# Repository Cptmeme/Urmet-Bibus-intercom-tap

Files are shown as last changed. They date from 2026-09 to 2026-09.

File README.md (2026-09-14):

# telefoon_input: Urmet Bibus VOP intercom tap

Reverse-engineering the Urmet intercom (Artico monitor 1705/1 on bracket 1705/954,
Bibus 2nd Ed. VOP) so it can be bridged into Home Assistant.

| Path | What |
|---|---|
| `bus_tap/` | KiCad project for the analog tap board (L1/L2 + C1/C2 to ESP32 ADC), JLCPCB files in `bus_tap/jlc/` |
| `firmware/bus_tap_capture/` | ESP32 firmware streaming the tap's ADC channels over Wi-Fi/UDP |
| `host/` | `bustap`: record, analyse, decode and compare bus traffic |
| `docs/` | Urmet Bibus 2nd Ed. VOP technical manual, section 4B |
| `telefoon_input.kicad_sch` | reverse-engineered schematic of the AliExpress PC817 opto board |

Order of work: build the tap board, flash the firmware, run `bustap monitor` at the wall,
then record and decode. See `host/README.md`.

**Safety.** bus_tap GND is bus L2 and the tap is not isolated. While it is connected to
the intercom, the ESP32 runs from an isolated USB supply and talks over Wi-Fi only.

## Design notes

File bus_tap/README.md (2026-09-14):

# Urmet Bibus VOP — L1/L2 + C1/C2 analog tap

Front end that lets an ESP32 act as the oscilloscope we don't have, so we can
measure the modulation depth and bit timing on the Urmet door-phone bus.

Target hardware: **Urmet Bibus 2nd Ed. VOP**, Artico monitor Ref. 1705/1 on
bracket Ref. 1705/954. Manual in `../docs/`.

## Wiring

### Intercom side
| Board | Intercom terminal | Note |
|---|---|---|
| J1-1 | **L1** | bus positive (22.5 V idle as measured) |
| J1-2 | **L2** | becomes board GND |
| J2-1 | **C1** | floor call |
| J2-2 | **C2** | floor call |

Leave **VPI / VPU alone.** They carry the monitor's operating power
(700 mA, 16–18.5 Vdc), not just video.

### ESP32 side — J3
| J3 | ESP32 (classic DevKit) | Signal |
|---|---|---|
| 1 | 3V3 | supply for U1 |
| 2 | GND | **= bus L2** |
| 3 | GPIO34 | `ADC_DC`  — channel A, absolute bus voltage |
| 4 | GPIO35 | `ADC_AC`  — channel B, AC-coupled ×11 |
| 5 | GPIO36 (VP) | `ADC_FC` — channel C, floor call |

**Use ADC1 pins only.** ADC2 is unusable while Wi-Fi is on, and we need Wi-Fi
(see safety note below). GPIO34/35/36 are input-only, which suits analog.

## Channels

- **A — absolute.** R1/R2 divide by 11, U1A buffers, R3/C1 anti-alias at ~16 kHz.
  Window 0–34 V, so 22.5 V idle sits at 2.05 V. Shows big dips and the DC level.
- **B — AC-coupled, gain 11.** C2 blocks DC, R4/R5 re-bias to 1.65 V, U1B gains
  ×11. Net effect: **1 V of bus swing = 1 V at the ADC**, centred on 1.65 V,
  ±1.5 V before clipping, 3.2 Hz high-pass. This is the channel that will show
  small modulation and edges that channel A buries in quantisation noise.
- **C — floor call.** Same divider + buffer on C1/C2.

MCP6004 is CMOS (~1 pA bias), so the 1 MΩ divider costs ~1 µV of offset. Do not
substitute a bipolar op-amp such as LM324 — it is neither rail-to-rail nor
happy at 3.3 V, and its bias current would swamp the divider.

## Connector notes

There is **no separate external GND**. Board GND *is* bus L2 - it arrives on J1-2 and
leaves on J3-2 to the ESP32. Do not add a dedicated ground pin; the one thing this
board must not have is two references.

Mis-plugging is harmless: both bus channels use identical 1M/100k front ends, so
swapping the L1/L2 and C1/C2 headers does nothing bad, and reversing L1/L2 polarity
merely pins channel A at zero (D1 clamps at -0.3 V, the 1 M holds current to ~22 uA).

The one real risk is a wire that works loose and *dangles* behind the intercom, where
it could bridge L1 to L2. A disconnected tap is harmless - it is passive and
high-impedance, you just lose data - but a flapping conductor on a shared bus is not.
Use short leads with heat-shrink strain relief, or fit keyed/latching connectors
(JST-XH is 2.54 mm pitch, polarised, and JLC-stocked) if you want it fit-and-forget.

## Safety

1. **This tap is NOT isolated** — board GND is bus L2. Power the ESP32 from an
   isolated USB wall wart and get data off over **Wi-Fi/UDP**. Never plug the
   laptop's USB in while J1 is connected to the bus; that would tie the
   building's bus rail to your laptop's ground.
2. **Bus loading:** 22.5 V / 1.1 MΩ ≈ **20 µA**. The manual specs the whole
   monitor's standby draw on L1/L2 as **1.6 mA max**, so this tap is ~1.3% of
   it. This is why the PC817 opto board must not go here — at 3.3 kΩ it would
   draw 5.9 mA, ~3.7× the entire monitor.
3. **JP1** links C2 to board GND. Fit it **only** after confirming with a
   multimeter that the C1/C2 loop shares a reference with L2. If that loop
   floats, leave JP1 open and sense C1/C2 with the separate opto board — C1/C2
   is local to this monitor only, so nothing there can affect neighbours.

## JLCPCB part status

Checked against JLCPCB's Economic Parts list (Basic + Preferred Extended = $0 feeder
fee). Everything below is in that list **except** the three noted.

| Part | LCSC | Library | Note |
|---|---|---|---|
| R 1k 0402 | C11702 | Basic | |
| R 10k 0402 | C25744 | Basic | |
| R 100k 0402 | C25741 | Basic | |
| R 1M 0805 | C17514 | Basic | **150 V rated** |
| C 10n 0402 | C15195 | Basic | |
| C 100n 0402 | C1525 | Basic | |
| C 1u 0402 | C52923 | Basic | |
| C 10u 0402 | C15525 | Basic | 6.3 V X5R |
| BAT54S SOT-23 | C7420333 | Preferred Ext. | $0 fee, 1.2 M in stock |
| MCP6004T-I/SL | C7378 | **Extended** | feeder fee |
| 2.54 mm 1x02 header | - | **Extended** | no connectors are economic parts |
| 2.54 mm 1x05 header | - | **Extended** | " |

**3 unique Extended parts -> roughly $9 in one-off feeder fees.**

Why R1/R9 stay 0805: the 0402 1M (C26083) is rated **50 V**, the 0805 1M (C17514)
is **150 V**. R1/R9 take 10/11 of anything appearing on L1/L2, and the door strike
is inductive. This is the one place the extra millimetre is worth it.

### Cutting the feeder fees to zero

1. **Hand-solder the four headers.** They are the only through-hole parts and the
   only reason to pay for THT assembly at all. Removes 2 of the 3 Extended parts.
2. **Swap the quad for 2x MCP6002 (C7377, Preferred Extended, $0).** Two SOIC-8
   instead of one SOIC-14. Only 3 of the 4 amplifiers are used, so two duals give
   the same single spare. Costs a schematic edit and one more decoupling cap.

### Do NOT substitute LM324

`LM324DT` (C71035) is a Basic part, SOIC-14, and pin-compatible with the MCP6004.
It will not work here. Its input common-mode range is Vee to Vcc-1.5 V, i.e. 0 to
**1.8 V** on a 3.3 V rail - but channel A's input sits at **2.05 V**, outside that
range entirely. Its 45 nA input bias across the 90.9 kOhm source would also add
several mV of offset where the MCP6004's ~1 pA adds a microvolt. Same footprint,
free, and completely wrong.

## Files

| File | Purpose |
|---|---|
| `bom.csv` | full engineering BOM (refs, values, footprints, LCSC, JLC library) |
| `bom_jlcpcb.csv` | **upload this to JLCPCB** - Comment / Designator / Footprint / LCSC Part #, SMD only |
| `bus_tap.pdf` | schematic print |
| `erc.rpt` | ERC report |

`bom_jlcpcb.csv` covers 21 assembled parts over 10 lines. J1, J2, J3 and JP1 are
deliberately excluded - they are the only through-hole parts, they are the only
Extended parts left once the MCP6004 fee is paid, and hand-fitting four headers takes
minutes. Designators are written as explicit lists (`R2,R4,R5,R6,R10`), not KiCad's
default ranges (`R4-R6`), which JLC's BOM parser does not understand.

Each symbol carries `LCSC` and `JLC` fields, so both BOMs regenerate straight from
the schematic.

## JLCPCB upload files (`jlc/`)

| File | Upload as |
|---|---|
| `bus_tap-gerbers.zip` | PCB (11 fab layers, gerber drill included) |
| `bom_jlc.csv` | BOM - `Comment / Designator / Footprint / LCSC Part #` |
| `cpl_jlc.csv` | CPL - `Designator / Mid X / Mid Y / Layer / Rotation` |

J1, J2, J3 and JP1 are excluded from both CSVs (hand-soldered). BOM and CPL
designators cross-check: 21 each, no orphans.

### CPL rotation corrections - ALREADY APPLIED to cpl_jlc.csv

JLC's library orientation differs from KiCad's for two packages here. Determined
empirically from JLC's upload preview, and **baked into `cpl_jlc.csv`**:

| Part | Package | KiCad rot | Correction | CPL value |
|---|---|---|---|---|
| D1 | SOT-23 | 0 | +180 | **180** |
| D2 | SOT-23 | 180 | +180 | **0** |
| U1 | SOIC-14 | 0 | -90 (90 CW) | **270** |

Rotation in the CPL is **counter-clockwise-positive**, matching KiCad's own pos file
(which emits -90 for C6/C7 and +90 for R10). KiCad places SOIC-14 with the long axis
vertical and pin 1 top-left; JLC's library has it horizontal, hence the 90 deg.

The 18 chip R/C parts need no correction - they are two-terminal and non-polarised,
so 0 vs 180 is electrically identical.

**Verification on next upload: the preview should need NO manual rotation.** If any of
these three still looks wrong, the correction above is stale - re-derive it rather than
nudging it in the preview.

## Status

- Schematic: complete, hand-tidied in eeschema, **ERC clean (0 violations)**, netlist verified unchanged.
- Footprints: **assigned on all 25 parts**, 9 distinct footprints, all verified present in the KiCad libraries.
- PCB: not started. Target is JLCPCB Economic PCBA. Run **Tools > Update PCB from Schematic (F8)** in the PCB editor to seed it.

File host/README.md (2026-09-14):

# bustap: record and decode the Urmet bus

Protocol-discovery tools for the bus_tap board. They don't assume an encoding: they
find activity, work out how bits are encoded from pulse timing, decode with every
plausible scheme, rank the results, and line up frames from different events so the
address, command and checksum fields stand out.

## Setup

```sh
cd host
python3 -m venv .venv
.venv/bin/pip install -r requirements.txt
.venv/bin/python -m unittest discover -s tests      # a few seconds, no hardware needed
```

Run commands from `host/` as `.venv/bin/python -m bustap ...`.

## At the intercom

1. Flash the firmware (see `firmware/bus_tap_capture/README.md`). Power the ESP32 from an
   **isolated** USB supply, wire J3, then J1 (L1/L2) and J2 (C1/C2).
2. **`bustap monitor`**: the first sanity check. Idle DC should read about **22.5 V**; ~0 V
   usually means L1/L2 are swapped, which is harmless. Watch `lost`, `gaps` and `ovf`
   stay at 0.
3. **Record labelled events**, one label per kind of event:
   ```sh
   bustap record --gated --label ring_own        # ring your own bell at the street panel
   bustap record --gated --label door_open       # press the door-release button
   bustap record --gated --label handset_up
   bustap record --gated --label floor_call      # your own landing button (C1/C2)
   ```
   Each burst of activity becomes its own file in `captures/`, with a second of history
   before the trigger. Calls to other flats also travel over L1/L2; capture a few, since
   the difference between your address and another is what exposes the address field.
4. **`bustap analyze captures/*.npz --plots plots/`**, per event: which channel was used,
   the pulse and gap clusters as multiples of one time unit, ranked encoding
   hypotheses, and the best decodes with their error counts. Look at the plots too.
5. **`bustap compare captures/*.npz`**, per bit position:
   `=` is identical everywhere (preamble/sync), `L` changes only between labels
   (address/command), `*` varies within a label (counter, checksum). It then searches
   for a checksum (sum, xor, CRC-8 variants) over the aligned frames.

## Reading the output honestly

- **`~ equally clean: ...`** means timing cannot choose between readings. Manchester and
  biphase-mark are *provably* interchangeable on the wire; a UART reading of fewer than
  four bytes can frame by chance. Run `compare` on both with `--decoder`, and keep the one
  that gives frames a stable preamble.
- **`CONFIRMED` checksums need at least 4 distinct frames.** With fewer, chance
  agreement across ~2500 combinations is likely and the result is marked `UNCONFIRMED`.
- **Frame edges.** A symbol at the bus's idle level at the start or end of a frame merges
  into the idle beside it. Manchester, UART, pulse-width and pulse-distance recover it.
  Biphase-mark can lose a final 0, and plain NRZ loses trailing idle-level bits: nothing
  on the wire marks where those frames end. A frame that is one bit value repeated
  (like `0x00` or `0xFF`) is ambiguous by half a bit in Manchester. Real frames with a
  preamble are not.
- **AC clipping.** Large dips saturate the AC channel. The report says so; timing is still
  good, and the DC channel carries the true levels.

## Without the intercom

```sh
bustap simulate manchester --payload a5120140 --label ring_own --out sim.npz
bustap analyze sim.npz
bustap fake-esp sim.npz --port 17777 &          # serves it over the real UDP protocol
bustap monitor --esp 127.0.0.1 --port 17777
```

`simulate` supports manchester, bmc, uart, pwm, pdm, nrz, fsk and dtmf, through a model
of the bus_tap channels and ESP32 ADC.

## Layout

| Module | Role |
|---|---|
| `protocol.py` | UDP wire format (mirrors `firmware/.../protocol.h`) |
| `record.py` | receiver, live monitor, fixed and activity-gated recording |
| `capture.py` | `.npz` capture files, raw codes to bus volts |
| `dsp.py` | noise, event detection, slicing, sub-sample edge timing |
| `infer.py` | duration clusters, time unit, encoding hypotheses |
| `decoders.py` | NRZ, UART, Manchester, biphase-mark, pulse-width, pulse-distance |
| `tones.py` | tone detection, FSK discriminator, DTMF |
| `compare.py` | frame alignment, field map, checksum search |
| `simulate.py`, `fake_esp.py` | synthetic traffic and a fake ESP for testing |

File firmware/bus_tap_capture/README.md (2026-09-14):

# bus_tap_capture

ESP32 firmware for the bus_tap board. Samples the three analog channels continuously
and streams them over Wi-Fi/UDP to the host tools in `host/`.

> **Safety.** bus_tap GND *is* Urmet bus L2. Flash and configure the ESP32 **before** it
> goes near the intercom. Once J1 is connected, power the ESP32 from an **isolated USB
> supply only** and never plug it into a computer. That is why data leaves over Wi-Fi.

## Build and flash (ESP-IDF 5.3)

```sh
cd firmware/bus_tap_capture
export IDF_PYTHON_ENV_PATH=$HOME/.espressif/python_env/idf5.3_py3.13_env
. $HOME/esp/esp-idf/export.sh
idf.py set-target esp32
idf.py menuconfig          # "Bus tap capture": Wi-Fi SSID and password
idf.py -p /dev/cu.usbserial-XXXX flash monitor
```

`IDF_PYTHON_ENV_PATH` is needed on this machine: without it `export.sh` picks Homebrew's
Python 3.14 and looks for a py3.14 IDF environment that does not exist.

The Wi-Fi password is stored in plain text in `sdkconfig`; don't share that file.

## Wiring: ESP32 DevKit to bus_tap J3

| J3 | ESP32 | Signal |
|---|---|---|
| 1 | 3V3 | op-amp supply |
| 2 | GND | = bus L2 |
| 3 | GPIO34 | DC, absolute bus voltage |
| 4 | GPIO35 | AC, bus swing |
| 5 | GPIO36 (VP) | FC, floor call |

ADC1 pins only; ADC2 does not work while Wi-Fi is on. Pins are configurable in menuconfig.

## Behaviour

- **Rate.** 60 kS/s total by default, shared by the enabled channels (20 kS/s each with
  all three). The host can change it at runtime, e.g.
  `python -m bustap monitor --ch AC --rate 60000` puts all 60 kS/s on the AC channel.
  Worth doing for fine timing: the board's anti-alias filter sits at ~16 kHz, above the
  10 kHz Nyquist limit you get with three channels sharing 60 kS/s.
- **Streaming** runs only while a host keeps sending `UBTHELLO` (5 s lease), to the host
  that sent the most recent one.
- **INFO** once a second: configuration, the eFuse calibration table, DMA overflow and
  Wi-Fi TX-drop counters, RSSI.
- **Protocol** is defined in `main/protocol.h`; `host/tests/test_protocol.py` compiles it
  and checks `host/bustap/protocol.py` against it.

## What has and hasn't been verified

Verified: builds for ESP32 on IDF 5.3.2 with no warnings from `main/`; the protocol
layout matches the host byte for byte; the host recorder, gap accounting and gated
recording pass against a protocol-identical fake on localhost.

**Not yet verified on hardware:** sustained 60 kS/s over your actual Wi-Fi, the real
ADC sample rate (the host measures it against `esp_timer`, so a few percent of error
is corrected rather than silently scaling pulse widths), and ADC behaviour at the
extremes. The ESP32 ADC compresses above about 2.45 V at 12 dB attenuation, so AC
channel swings beyond roughly +0.8 V read low. Timing is unaffected.

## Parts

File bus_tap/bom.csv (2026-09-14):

Reference | Value | Footprint | LCSC
C1,C4,C5 | 10n | Capacitor_SMD:C_0402_1005Metric | C15195
C2 | 1u | Capacitor_SMD:C_0402_1005Metric | C52923
C3,C7 | 10u | Capacitor_SMD:C_0402_1005Metric | C15525
C6 | 100n | Capacitor_SMD:C_0402_1005Metric | C1525
D1,D2 | BAT54S | Package_TO_SOT_SMD:SOT-23 | C7420333
J1 | L1/L2 | Connector_PinHeader_2.54mm:PinHeader_1x02_P2.54mm_Vertical
J2 | C1/C2 | Connector_PinHeader_2.54mm:PinHeader_1x02_P2.54mm_Vertical
J3 | ESP32 DevKit | Connector_PinHeader_2.54mm:PinHeader_1x05_P2.54mm_Vertical
JP1 | JUMPER | Connector_PinHeader_2.54mm:PinHeader_1x02_P2.54mm_Vertical
R1,R9 | 1M | Resistor_SMD:R_0805_2012Metric | C17514
R2,R4-R6,R10 | 100k | Resistor_SMD:R_0402_1005Metric | C25741
R3,R8,R11 | 1k | Resistor_SMD:R_0402_1005Metric | C11702
R7 | 10k | Resistor_SMD:R_0402_1005Metric | C25744
U1 | MCP6004 | Package_SO:SOIC-14_3.9x8.7mm_P1.27mm | C7378

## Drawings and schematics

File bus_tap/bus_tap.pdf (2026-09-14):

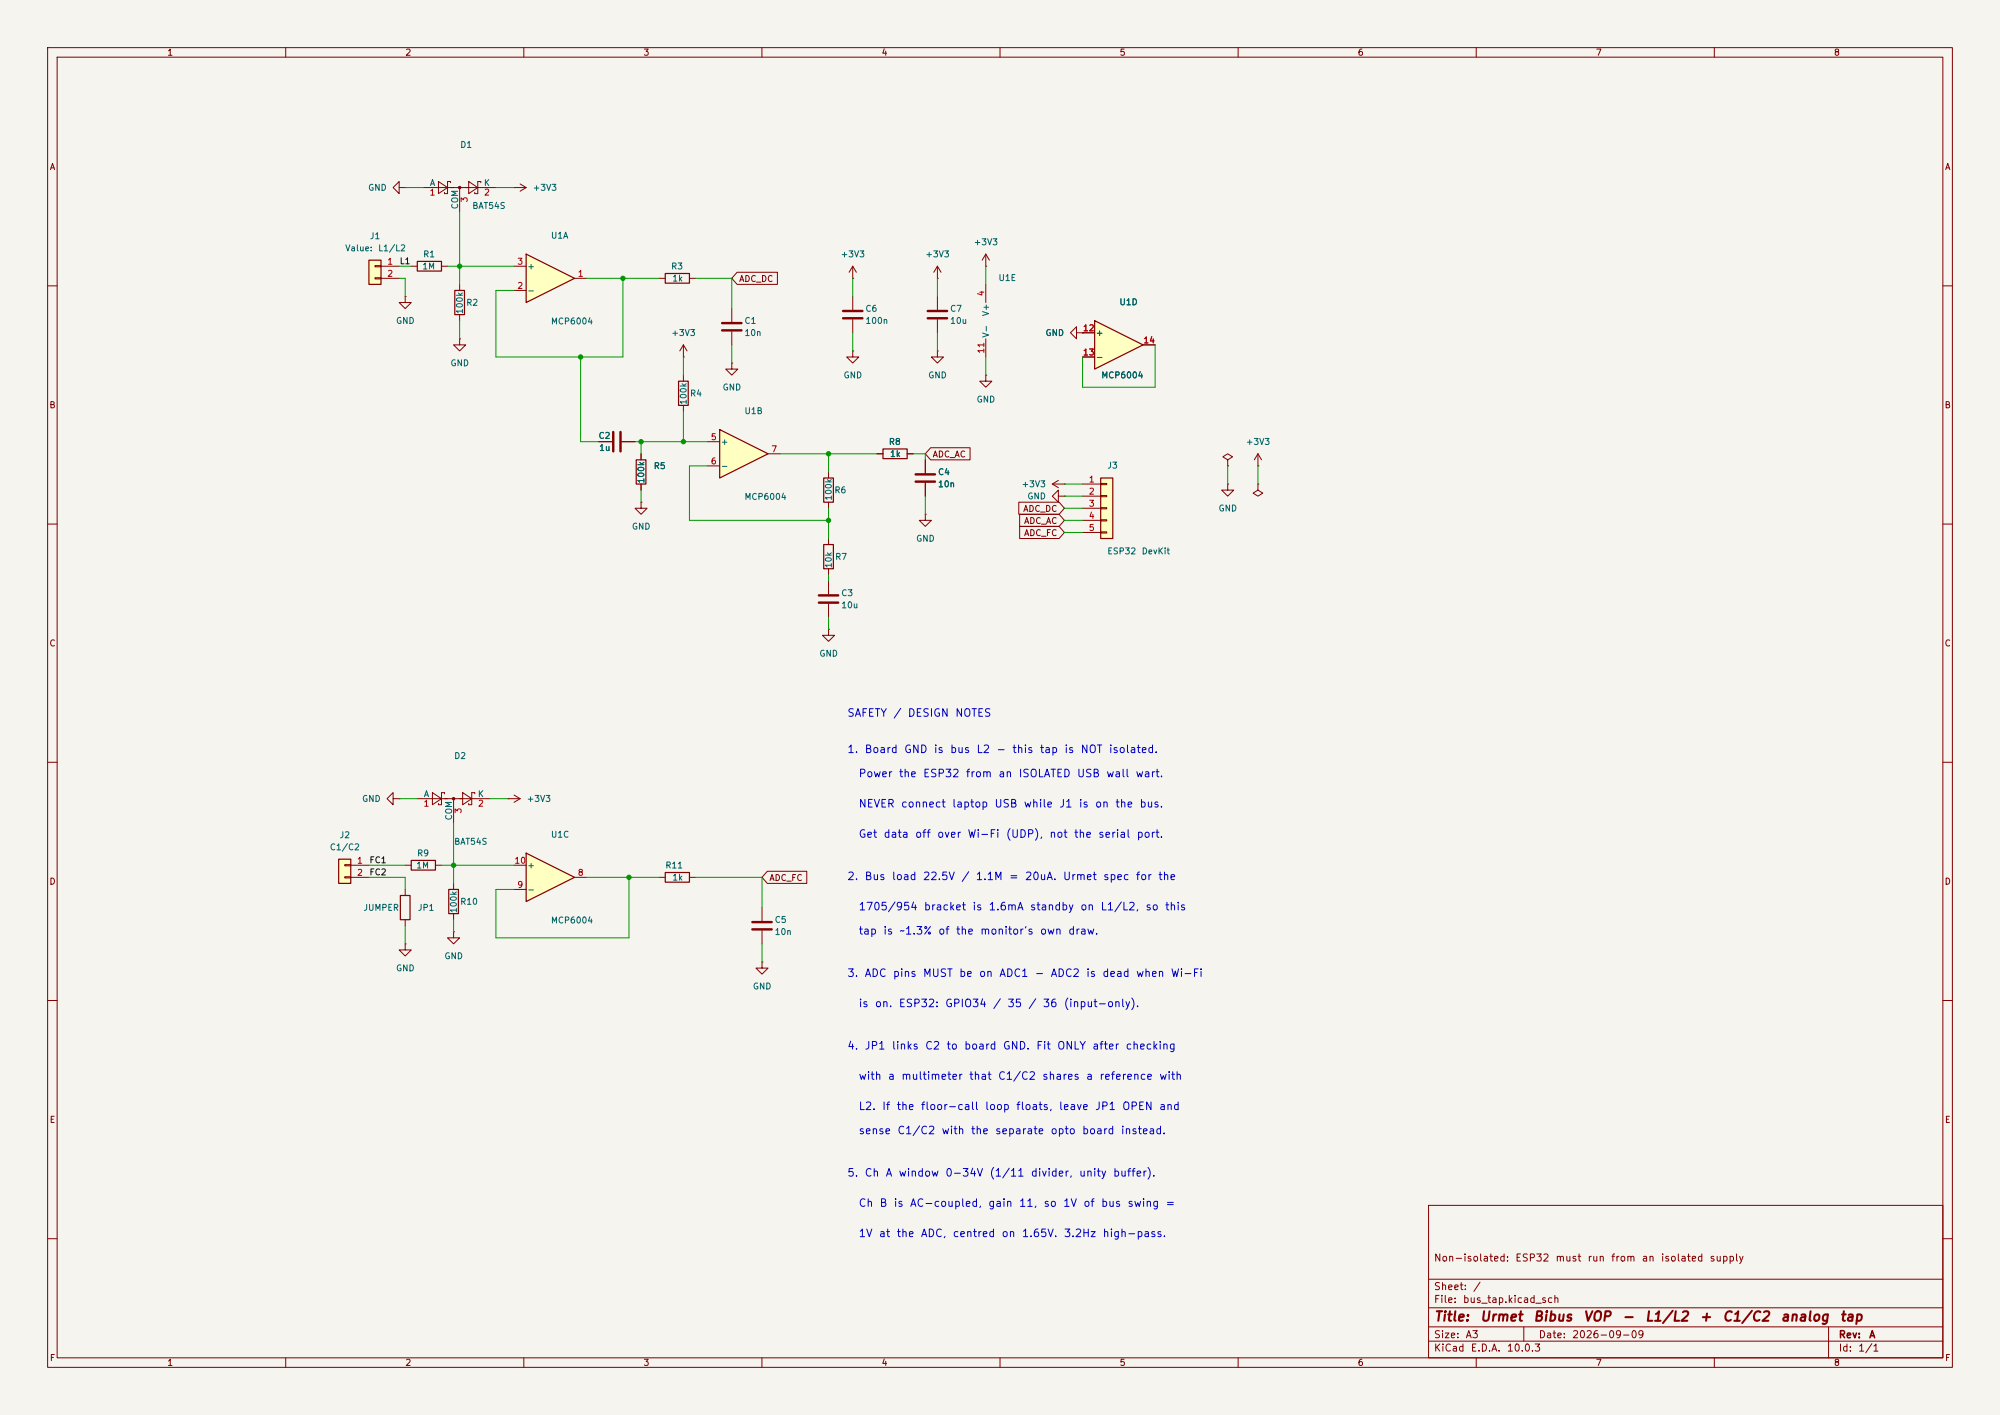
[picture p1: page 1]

1. Board GND is bus L2 - this tap is NOT isolated.

Power the ESP32 from an ISOLATED USB wall wart.

NEVER connect laptop USB while J1 is on the bus.

Get data off over Wi-Fi (UDP), not the serial port.

2. Bus load 22.5V / 1.1M = 20uA. Urmet spec for the

1705/954 bracket is 1.6mA standby on L1/L2, so this

tap is ~1.3% of the monitor's own draw.

3. ADC pins MUST be on ADC1 - ADC2 is dead when Wi-Fi

is on. ESP32: GPIO34 / 35 / 36 (input-only).

4. JP1 links C2 to board GND. Fit ONLY after checking

with a multimeter that C1/C2 shares a reference with

L2. If the floor-call loop floats, leave JP1 OPEN and

5. Ch A window 0-34V (1/11 divider, unity buffer).

Ch B is AC-coupled, gain 11, so 1V of bus swing =

1V at the ADC, centred on 1.65V. 3.2Hz high-pass.

Non-isolated: ESP32 must run from an isolated supply

Sheet: /
File: bus_tap.kicad_sch
Title: Urmet Bibus VOP - L1/L2 + C1/C2 analog tap

Size: A3 | Rev: A
KiCad E.D.A. 10.0.3 | Id: 1/1 | F Date: 2026-09-09

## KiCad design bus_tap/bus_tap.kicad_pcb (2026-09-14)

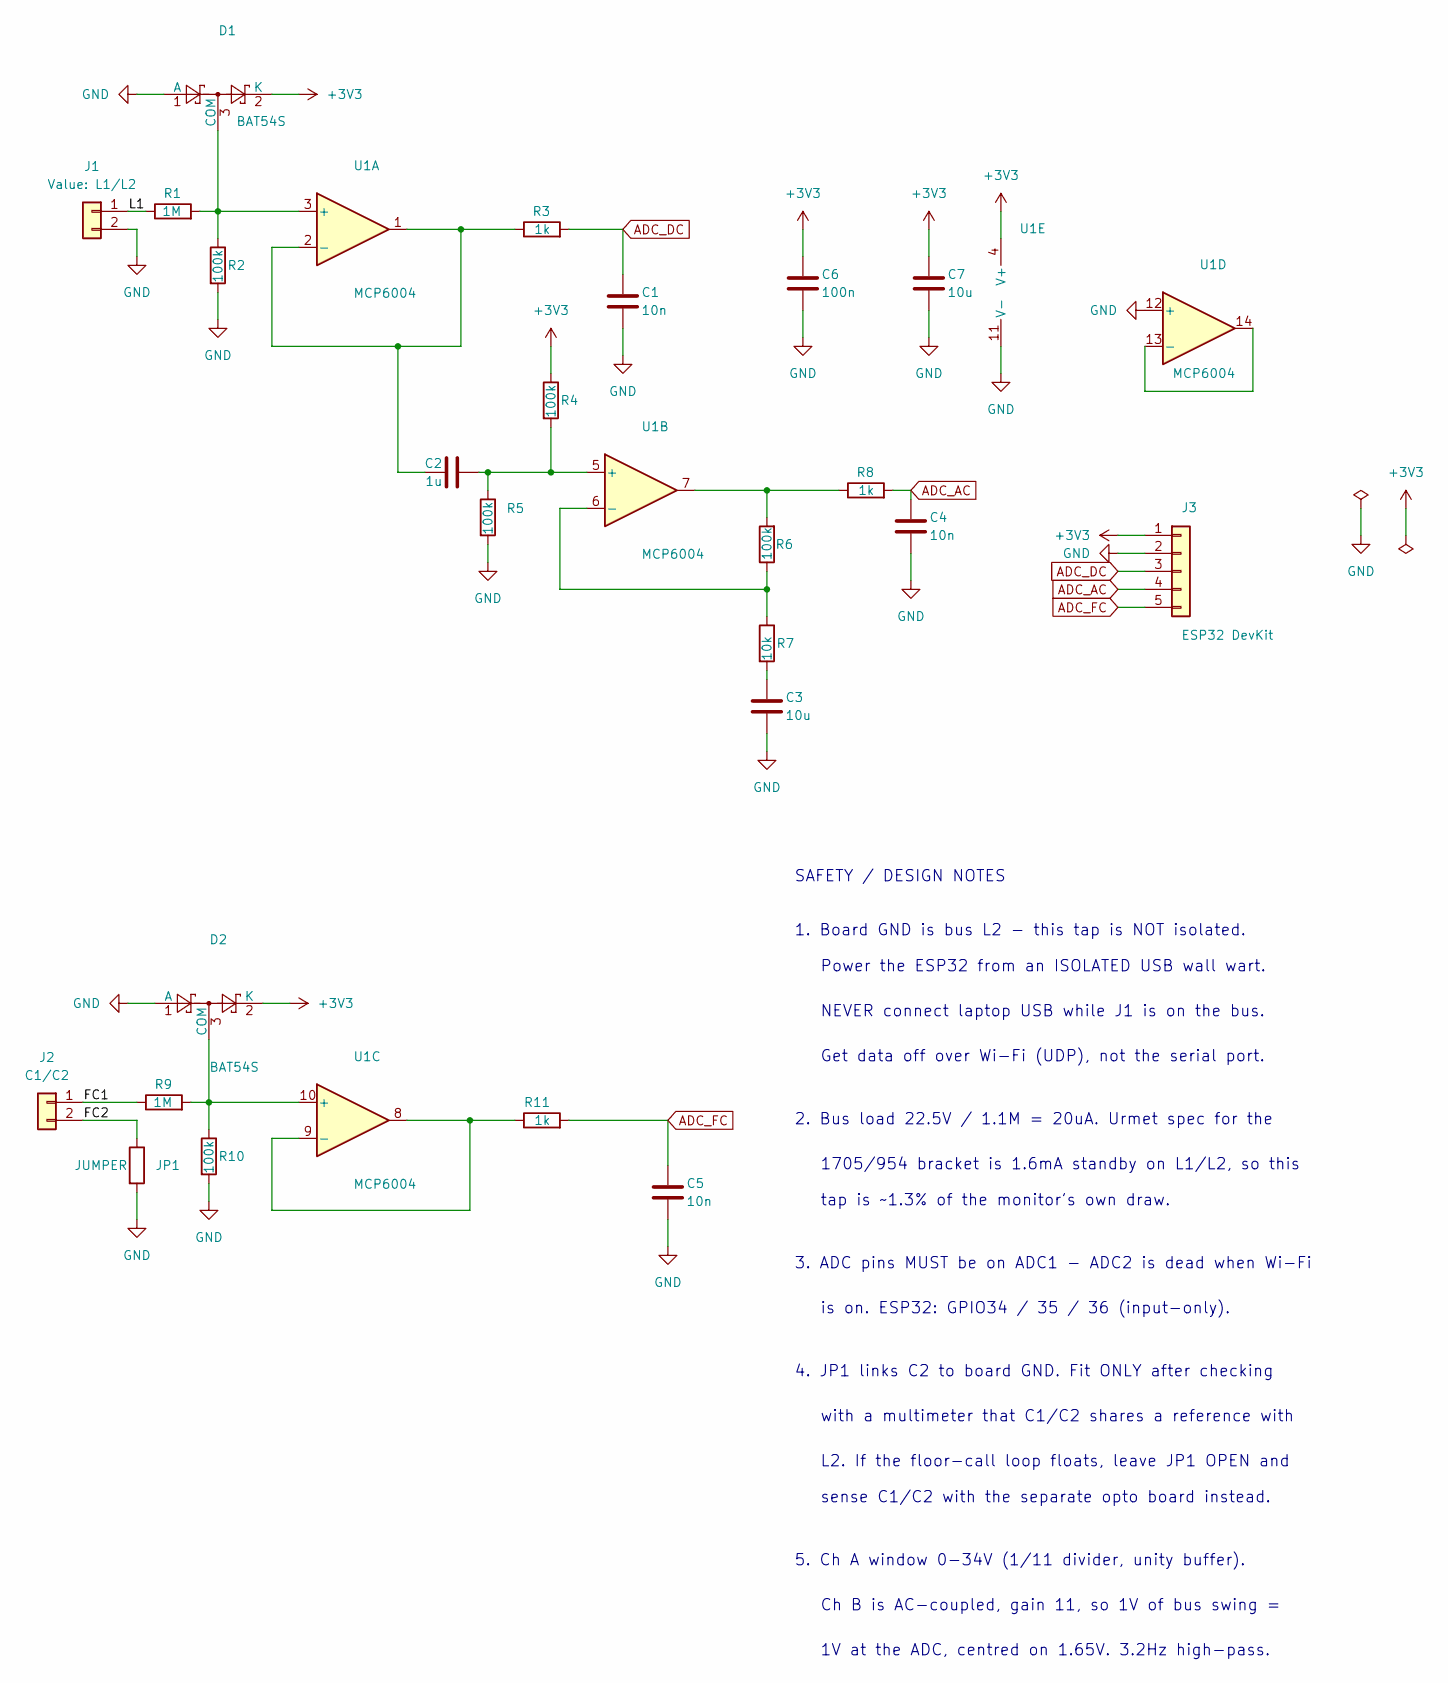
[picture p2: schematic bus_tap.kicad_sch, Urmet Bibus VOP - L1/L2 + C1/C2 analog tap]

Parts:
C1, C4, C5: 10n; C_0402_1005Metric; LCSC C15195
C2: 1u; C_0402_1005Metric; LCSC C52923
C3, C7: 10u; C_0402_1005Metric; LCSC C15525
C6: 100n; C_0402_1005Metric; LCSC C1525
D1, D2: BAT54S; SOT-23; LCSC C7420333
J1: L1/L2; PinHeader_1x02_P2.54mm_Vertical; JLC Extended - hand solder, not in JLC BOM
J2: C1/C2; PinHeader_1x02_P2.54mm_Vertical; JLC Extended - hand solder, not in JLC BOM
J3: ESP32 DevKit; PinHeader_1x05_P2.54mm_Vertical; JLC Extended - hand solder, not in JLC BOM
JP1: JUMPER; PinHeader_1x02_P2.54mm_Vertical; JLC Extended - hand solder, not in JLC BOM
R1, R9: 1M; R_0805_2012Metric; LCSC C17514
R2, R4, R5, R6, R10: 100k; R_0402_1005Metric; LCSC C25741
R3, R8, R11: 1k; R_0402_1005Metric; LCSC C11702
R7: 10k; R_0402_1005Metric; LCSC C25744
U1: MCP6004; SOIC-14_3.9x8.7mm_P1.27mm; LCSC C7378

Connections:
+3V3: C6.1, C7.1, D1.2 (K), D2.2 (K), J3.1, R4.1, U1.4 (V+)
/FC1: J2.1, R9.1
/FC2: J2.2, JP1.1
/L1: J1.1, R1.1
ADC_AC: C4.1, J3.4, R8.2
ADC_DC: C1.1, J3.3, R3.2
ADC_FC: C5.1, J3.5, R11.2
GND: C1.2, C3.2, C4.2, C5.2, C6.2, C7.2, D1.1 (A), D2.1 (A), J1.2, J3.2, JP1.2, R2.2, R5.2, R10.2, U1.11 (V-), U1.12 (+)
unnamed: C3.1, R7.2
unnamed: D1.3 (COM), R1.2, R2.1, U1.3 (+)
unnamed: D2.3 (COM), R9.2, R10.1, U1.10 (+)
unnamed: R6.2, R8.1, U1.7
unnamed: C2.1, R3.1, U1.1, U1.2 (-)
unnamed: C2.2, R4.2, R5.1, U1.5 (+)
unnamed: R6.1, R7.1, U1.6 (-)
unnamed: R11.1, U1.8, U1.9 (-)
unnamed: U1.13 (-), U1.14

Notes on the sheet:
Ch B is AC-coupled, gain 11, so 1V of bus swing =
tap is ~1.3% of the monitor's own draw.
4. JP1 links C2 to board GND. Fit ONLY after checking
Power the ESP32 from an ISOLATED USB wall wart.
L2. If the floor-call loop floats, leave JP1 OPEN and
NEVER connect laptop USB while J1 is on the bus.
2. Bus load 22.5V / 1.1M = 20uA. Urmet spec for the
Get data off over Wi-Fi (UDP), not the serial port.
3. ADC pins MUST be on ADC1 - ADC2 is dead when Wi-Fi
1V at the ADC, centred on 1.65V. 3.2Hz high-pass.
1705/954 bracket is 1.6mA standby on L1/L2, so this
SAFETY / DESIGN NOTES
1. Board GND is bus L2 - this tap is NOT isolated.
sense C1/C2 with the separate opto board instead.
is on. ESP32: GPIO34 / 35 / 36 (input-only).
with a multimeter that C1/C2 shares a reference with
5. Ch A window 0-34V (1/11 divider, unity buffer).

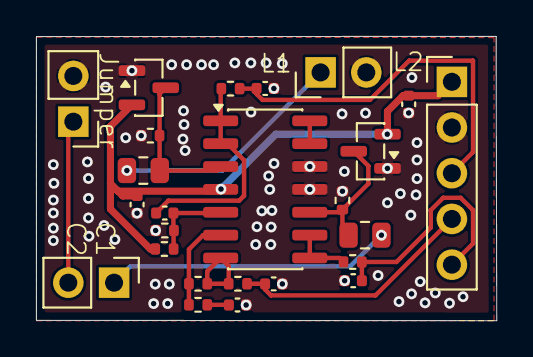
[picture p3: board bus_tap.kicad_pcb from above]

Board: 2 copper layers, 25.6 x 15.8 mm, 25 parts (0 on the bottom side), 17 nets.

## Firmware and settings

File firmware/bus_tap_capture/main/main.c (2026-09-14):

/*
 * bus_tap_capture: stream the bus_tap board's three ADC channels over Wi-Fi/UDP.
 *
 * SAFETY: bus_tap GND is Urmet bus L2. While J1 is connected to the intercom, power
 * this ESP32 from an isolated USB supply and never plug it into a computer.
 * Data leaves over Wi-Fi precisely so no wired connection is needed.
 */
#include <stdlib.h>
#include <string.h>

#include "esp_log.h"
#include "esp_timer.h"
#include "lwip/sockets.h"
#include "nvs_flash.h"
#include "sdkconfig.h"

#include "adc_stream.h"
#include "protocol.h"
#include "wifi.h"

static const char *TAG = "bus_tap";

/* "UBTHELLO rate=60000 ch=DC,AC" -> rate 60000, mask 0b011. Absent options stay 0. */
static void parse_hello(const char *msg, uint32_t *rate, uint8_t *mask)
{
    *rate = 0;
    *mask = 0;
    const char *r = strstr(msg, "rate=");
    if (r) *rate = strtoul(r + 5, NULL, 10);

    const char *c = strstr(msg, "ch=");
    if (!c) return;
    for (c += 3; *c && *c != ' ';) {
        const char *end = c;
        while (*end && *end != ',' && *end != ' ') end++;
        int idx = adc_stream_channel_index(c, end - c);
        if (idx >= 0) *mask |= 1u << idx;
        c = (*end == ',') ? end + 1 : end;
    }
}

void app_main(void)
{
    esp_err_t err = nvs_flash_init();
    if (err == ESP_ERR_NVS_NO_FREE_PAGES || err == ESP_ERR_NVS_NEW_VERSION_FOUND) {
        ESP_ERROR_CHECK(nvs_flash_erase());
        err = nvs_flash_init();
    }
    ESP_ERROR_CHECK(err);

    wifi_start();
    wifi_wait_connected();

    int sock = socket(AF_INET, SOCK_DGRAM, IPPROTO_UDP);
    struct sockaddr_in addr = {
        .sin_family = AF_INET,
        .sin_port = htons(CONFIG_BUS_TAP_UDP_PORT),
        .sin_addr.s_addr = htonl(INADDR_ANY),
    };
    if (sock < 0 || bind(sock, (struct sockaddr *)&addr, sizeof(addr)) < 0) {
        ESP_LOGE(TAG, "UDP socket/bind failed");
        abort();
    }
    struct timeval tv = {.tv_sec = 1};
    setsockopt(sock, SOL_SOCKET, SO_RCVTIMEO, &tv, sizeof(tv));

    adc_stream_start(sock);
    ESP_LOGI(TAG, "waiting for %s on UDP %d", BT_HELLO, CONFIG_BUS_TAP_UDP_PORT);

    static uint8_t info[1400];
    char rx[128];
    int64_t last_info_us = 0;

    for (;;) {
        struct sockaddr_in src;
        socklen_t src_len = sizeof(src);
        int n = recvfrom(sock, rx, sizeof(rx) - 1, 0, (struct sockaddr *)&src, &src_len);
        bool reply = false;
        if (n > 0) {
            rx[n] = '\0';
            if (strncmp(rx, BT_HELLO, strlen(BT_HELLO)) == 0) {
                uint32_t rate;
                uint8_t mask;
                parse_hello(rx, &rate, &mask);
                if (!adc_stream_request_config(rate, mask)) ESP_LOGW(TAG, "ignoring invalid config in: %s", rx);
                adc_stream_touch_client(&src);
                reply = true; /* lets the host discover this ESP from a broadcast HELLO */
            }
        }

        struct sockaddr_in client;
        int64_t now = esp_timer_get_time();
        if (adc_stream_get_client(&client) && (reply || now - last_info_us > 1000000)) {
            size_t len = adc_stream_build_info(info, sizeof(info));
            if (len) sendto(sock, info, len, 0, (struct sockaddr *)&client, sizeof(client));
            last_info_us = now;
        }
    }
}

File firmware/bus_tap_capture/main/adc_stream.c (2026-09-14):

#include <inttypes.h>
#include <stdarg.h>
#include <stdio.h>
#include <string.h>
#include <strings.h>

#include "esp_adc/adc_cali.h"
#include "esp_adc/adc_cali_scheme.h"
#include "esp_adc/adc_continuous.h"
#include "esp_attr.h"
#include "esp_log.h"
#include "esp_timer.h"
#include "freertos/FreeRTOS.h"
#include "freertos/task.h"
#include "sdkconfig.h"
#include "soc/soc_caps.h"

#include "adc_stream.h"
#include "protocol.h"
#include "wifi.h"

_Static_assert(sizeof(bt_hdr_t) == BT_HDR_SIZE, "bt_hdr_t layout drifted from protocol.h");

static const char *TAG = "adc";

#if CONFIG_IDF_TARGET_ESP32 || CONFIG_IDF_TARGET_ESP32S2
#define ADC_FORMAT      ADC_DIGI_OUTPUT_FORMAT_TYPE1
#define ADC_GET_CH(p)   ((p)->type1.channel)
#define ADC_GET_DATA(p) ((p)->type1.data)
#else
#define ADC_FORMAT      ADC_DIGI_OUTPUT_FORMAT_TYPE2
#define ADC_GET_CH(p)   ((p)->type2.channel)
#define ADC_GET_DATA(p) ((p)->type2.data)
#endif

#define ADC_ATTEN       ADC_ATTEN_DB_12
#define READ_LEN        (256 * SOC_ADC_DIGI_RESULT_BYTES)
#define POOL_LEN        (8192 * SOC_ADC_DIGI_RESULT_BYTES)
#define CLIENT_LEASE_US (5 * 1000 * 1000)
#define CAL_POINTS      17

typedef struct {
    const char *name;
    int gpio;
    adc_channel_t channel;
    bool valid;
} channel_t;

static channel_t s_ch[BT_MAX_CHANNELS] = {
    {.name = "DC", .gpio = CONFIG_BUS_TAP_GPIO_DC},
    {.name = "AC", .gpio = CONFIG_BUS_TAP_GPIO_AC},
    {.name = "FC", .gpio = CONFIG_BUS_TAP_GPIO_FC},
};
static int8_t s_phys_to_logical[16];

static adc_continuous_handle_t s_adc;
static adc_cali_handle_t s_cali;
static const char *s_cali_scheme = "none";
static int s_sock = -1;

/* Everything below is shared between the capture and control tasks. */
static portMUX_TYPE s_lock = portMUX_INITIALIZER_UNLOCKED;
static struct sockaddr_in s_client;
static int64_t s_client_seen_us;
static uint32_t s_rate_hz = CONFIG_BUS_TAP_SAMPLE_RATE;
static uint8_t s_mask;
static uint32_t s_epoch;
static uint32_t s_seq;
static bool s_pending;
static uint32_t s_pending_rate;
static uint8_t s_pending_mask;
static volatile uint32_t s_overflows;
static uint32_t s_tx_drops;

static bool IRAM_ATTR on_pool_ovf(adc_continuous_handle_t h, const adc_continuous_evt_data_t *e, void *u)
{
    s_overflows++;
    return false;
}

static int popcount8(uint8_t m)
{
    int n = 0;
    for (; m; m >>= 1) n += m & 1;
    return n;
}

static uint32_t next_seq(void)
{
    taskENTER_CRITICAL(&s_lock);
    uint32_t seq = s_seq++;
    taskEXIT_CRITICAL(&s_lock);
    return seq;
}

static void channels_init(void)
{
    memset(s_phys_to_logical, -1, sizeof(s_phys_to_logical));
    for (int i = 0; i < BT_MAX_CHANNELS; i++) {
        adc_unit_t unit;
        if (adc_continuous_io_to_channel(s_ch[i].gpio, &unit, &s_ch[i].channel) == ESP_OK && unit == ADC_UNIT_1) {
            s_ch[i].valid = true;
            s_mask |= 1u << i;
            s_phys_to_logical[s_ch[i].channel & 0xF] = i;
        } else {
            ESP_LOGE(TAG, "%s: GPIO%d is not an ADC1 input, channel disabled", s_ch[i].name, s_ch[i].gpio);
        }
    }
}

static void cali_init(void)
{
#if ADC_CALI_SCHEME_CURVE_FITTING_SUPPORTED
    adc_cali_curve_fitting_config_t curve = {
        .unit_id = ADC_UNIT_1,
        .chan = s_ch[0].channel,
        .atten = ADC_ATTEN,
        .bitwidth = ADC_BITWIDTH_12,
    };
    if (adc_cali_create_scheme_curve_fitting(&curve, &s_cali) == ESP_OK) {
        s_cali_scheme = "curve_fitting";
        return;
    }
#endif
#if ADC_CALI_SCHEME_LINE_FITTING_SUPPORTED
    adc_cali_line_fitting_config_t line = {
        .unit_id = ADC_UNIT_1,
        .atten = ADC_ATTEN,
        .bitwidth = ADC_BITWIDTH_12,
#if CONFIG_IDF_TARGET_ESP32
        .default_vref = 1100,
#endif
    };
    if (adc_cali_create_scheme_line_fitting(&line, &s_cali) == ESP_OK) {
        s_cali_scheme = "line_fitting";
        return;
    }
#endif
    ESP_LOGW(TAG, "no ADC calibration scheme; host will assume a nominal transfer curve");
}

static esp_err_t adc_apply(uint32_t rate_hz, uint8_t mask)
{
    adc_digi_pattern_config_t pattern[SOC_ADC_PATT_LEN_MAX] = {0};
    int n = 0;
    for (int i = 0; i < BT_MAX_CHANNELS; i++) {
        if (!(mask & (1u << i)) || !s_ch[i].valid) continue;
        pattern[n].atten = ADC_ATTEN;
        pattern[n].channel = s_ch[i].channel & 0x7;
        pattern[n].unit = ADC_UNIT_1;
        pattern[n].bit_width = SOC_ADC_DIGI_MAX_BITWIDTH;
        n++;
    }
    if (n == 0) return ESP_ERR_INVALID_ARG;
    adc_continuous_config_t cfg = {
        .pattern_num = n,
        .adc_pattern = pattern,
        .sample_freq_hz = rate_hz,
        .conv_mode = ADC_CONV_SINGLE_UNIT_1,
        .format = ADC_FORMAT,
    };
    return adc_continuous_config(s_adc, &cfg);
}

void adc_stream_touch_client(const struct sockaddr_in *addr)
{
    taskENTER_CRITICAL(&s_lock);
    s_client = *addr;
    s_client_seen_us = esp_timer_get_time();
    taskEXIT_CRITICAL(&s_lock);
}

bool adc_stream_get_client(struct sockaddr_in *out)
{
    taskENTER_CRITICAL(&s_lock);
    int64_t seen = s_client_seen_us;
    *out = s_client;
    taskEXIT_CRITICAL(&s_lock);
    return seen != 0 && esp_timer_get_time() - seen < CLIENT_LEASE_US;
}

int adc_stream_channel_index(const char *name, size_t len)
{
    for (int i = 0; i < BT_MAX_CHANNELS; i++) {
        if (strlen(s_ch[i].name) == len && strncasecmp(s_ch[i].name, name, len) == 0) return i;
    }
    return -1;
}

bool adc_stream_request_config(uint32_t rate_hz, uint8_t mask)
{
    if (rate_hz && (rate_hz < SOC_ADC_SAMPLE_FREQ_THRES_LOW || rate_hz > SOC_ADC_SAMPLE_FREQ_THRES_HIGH)) return false;
    uint8_t valid = 0;
    for (int i = 0; i < BT_MAX_CHANNELS; i++) valid |= s_ch[i].valid ? (1u << i) : 0;
    if (mask & ~valid) return false;

    taskENTER_CRITICAL(&s_lock);
    uint32_t rate = rate_hz ? rate_hz : s_rate_hz;
    uint8_t m = mask ? mask : s_mask;
    if (rate != s_rate_hz || m != s_mask) {
        s_pending_rate = rate;
        s_pending_mask = m;
        s_pending = true;
    }
    taskEXIT_CRITICAL(&s_lock);
    return true;
}

typedef struct {
    char *p;
    size_t cap, n;
    bool ok;
} sbuf_t;

static void sb_printf(sbuf_t *b, const char *fmt, ...) __attribute__((format(printf, 2, 3)));
static void sb_printf(sbuf_t *b, const char *fmt, ...)
{
    if (!b->ok) return;
    va_list ap;
    va_start(ap, fmt);
    int r = vsnprintf(b->p + b->n, b->cap - b->n, fmt, ap);
    va_end(ap);
    if (r < 0 || (size_t)r >= b->cap - b->n) {
        b->ok = false;
        return;
    }
    b->n += r;
}
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
